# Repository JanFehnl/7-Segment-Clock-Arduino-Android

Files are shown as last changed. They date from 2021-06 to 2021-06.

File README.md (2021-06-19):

# 7 Segment Clock Arduino Android
This is an digital 7 segment clock controlled with an Arduino and an android smartphone via Bluetooth. You don't need a real time clock module.

## Required Components:
  1. Arduino Nano or similar
  2. Low Energy Bluetooth Module (HC-05 oder similar)
  3. 220Ω resistor
  4. 12V power supply with Terminal
  5. 1.5m WS2811 LED-Strip
  6. wires
  7. 4 nails
  8. 16 M3*5+ bolts with nuts

## Step by step guide:
  1. 3D print the clock
      - Black:
        - 1 * MainLO.stl ①
        - 1 * MainLI.stl
        - 1 * MainRI.stl
        - 1 * MainRO.stl
        - 2 * Middle.stl
      - White:
        - 30 * Segment.stl (Layer Height = 0.1mm && Vase Mode on)
  3. Upload the Arduino Sketch to the Arduino.
  4. solder the components as shown in the following picture:

PlanFinal

4. Download the Android App from the Google Play Store:
https://play.google.com/store/apps/details?id=com.JanFehnl.Uhr

5. If the time is not exact, then change the value of the variable "TimeCorrection" in the Arduino Sketch so that the deviation of the time is as small as possible. If the clock is slow, then increase the value slightly, if the clock is fast, then decrease the value of the variable.

① If you have the Arduino outside the clock and only need the three cables to the LED strip, then use V1. If you want to mount the Arduino and the terminal of the 12V power supply inside the clock, then print V2 to be able to lead the two cables into the clock.

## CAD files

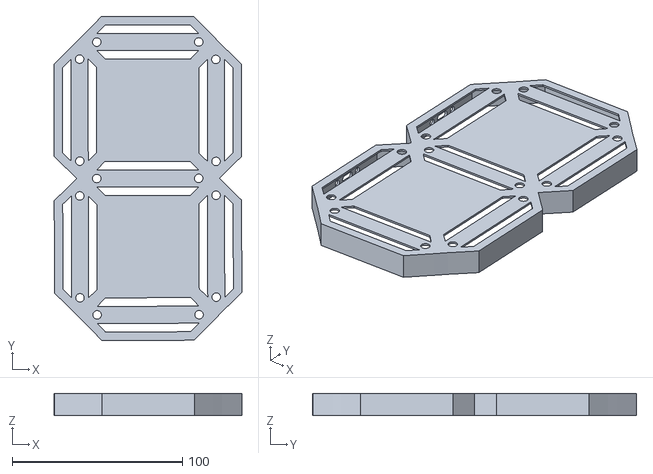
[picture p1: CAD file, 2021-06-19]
3DModels/MainLOV2.stl
110.1 x 190.1 x 13.0

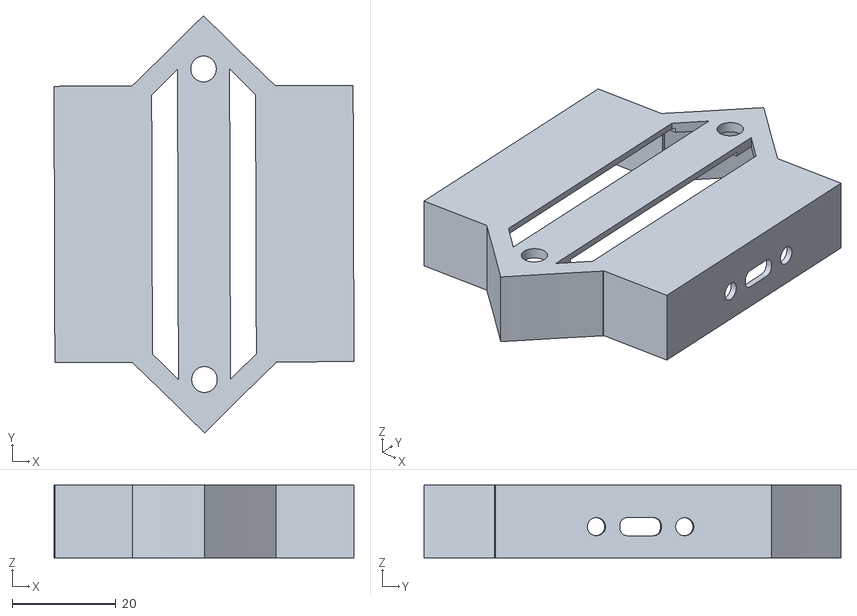
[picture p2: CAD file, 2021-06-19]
3DModels/Middle.stl
57.8 x 80.3 x 14.0

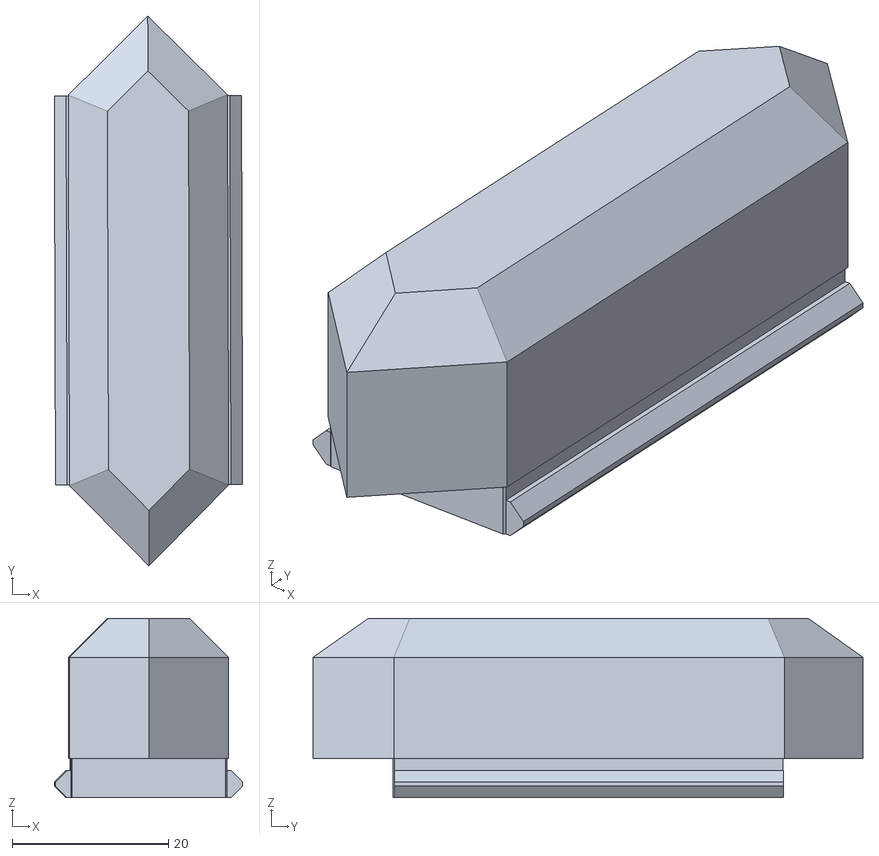
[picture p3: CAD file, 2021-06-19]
3DModels/Segment.stl
24.2 x 70.5 x 23.0

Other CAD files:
3DModels/MainLOV1.stl
3DModels/MainLI.stl
3DModels/MainLO.stl
3DModels/MainRO.stl
3DModels/MainRI.stl

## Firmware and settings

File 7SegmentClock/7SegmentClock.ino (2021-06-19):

#include <FastLED.h>

#define Num_Strip1 30
struct CRGB Strip1[Num_Strip1];

byte Red[5] = {255, 255, 255, 255};
byte Green[5] = {255, 255, 255, 255};
byte Blue[5] = {255, 255, 255, 255};
byte State;
byte Sekunde = 0;
byte MinuteUmspringen;
bool ValueIsComing = false;
unsigned long timeNow = 0;
unsigned long timeLast = 0;
int seconds = 0;
int minutes = 33;
int hours = 12;
int TimeCorrection = 1060;
int CaseNum;
char Case;

void setup()
{
  Serial.begin(9600);
  FastLED.addLeds<WS2811, 6, BRG>(Strip1, Num_Strip1);
}

void loop()
{
  timeNow = millis() / TimeCorrection;
  seconds = timeNow - timeLast;

  Sekunde = seconds;
  int ZeitInSekunden = Sekunde;
  int Minute = minutes;
  int Stunde = hours;

  if (MinuteUmspringen != Minute)
  {
    ShowDigit(0, Stunde / 10, 0);
    ShowDigit(7, Stunde % 10, 1);
    ShowDigit(16, Minute / 10, 2);
    ShowDigit(23, Minute % 10, 3);
    MinuteUmspringen = Minute;
  }
  if (ZeitInSekunden % 2 == 1)
  {
    Strip1[14] = CRGB(Red[4], Green[4], Blue[4]);
    Strip1[15] = CRGB(Red[4], Green[4], Blue[4]);
  }
  else
  {
    Strip1[14] = CRGB(Red[4] / 5, Green[4] / 5, Blue[4] / 5);
    Strip1[15] = CRGB(Red[4] / 5, Green[4] / 5, Blue[4] / 5);
  }

  if (seconds == 60)
  {
    timeLast = timeNow;
    minutes = minutes + 1;
  }

  if (minutes == 60)
  {
    minutes = 0;
    hours = hours + 1;
  }

  if (Serial.available())
  {
    if (ValueIsComing)
    {
      long int a = Serial.read();
      if (Case == 'a')
      {
        switch (CaseNum)
        {
        case 0:
          hours = a;
          CaseNum++;
          break;

        case 1:
          minutes = a;
          CaseNum++;
          break;

        case 2:
          timeLast = timeNow - a;
          ValueIsComing = false;
          break;

        default:
          break;
        }
      }
      else if (Case == 'b')
      {
        switch (CaseNum)
        {
        case 0:
          State = a;
          CaseNum++;
          break;

        case 1:
          if (State == 0 || State == 1 || State == 2 || State == 3)
          {
            Red[State] = a;
          }
          else if (State == 4)
          {
            Red[0] = a;
            Red[1] = a;
          }
          else if (State == 5)
          {
            Red[2] = a;
            Red[3] = a;
          }
          else if (State == 6)
          {
            Red[0] = a;
            Red[1] = a;
            Red[2] = a;
            Red[3] = a;
            Red[4] = a;
          }
          else if (State == 7)
          {
            Red[4] = a;
          }
          CaseNum++;
          break;

        case 2:
          if (State == 0 || State == 1 || State == 2 || State == 3)
          {
            Green[State] = a;
          }
          else if (State == 4)
          {
            Green[0] = a;
            Green[1] = a;
          }
          else if (State == 5)
          {
            Green[2] = a;
            Green[3] = a;
          }
          else if (State == 6)
          {
            Green[0] = a;
            Green[1] = a;
            Green[2] = a;
            Green[3] = a;
            Green[4] = a;
          }
          else if (State == 7)
          {
            Green[4] = a;
          }
          CaseNum++;
          break;

        case 3:
          if (State == 0 || State == 1 || State == 2 || State == 3)
          {
            Blue[State] = a;
          }
          else if (State == 4)
          {
            Blue[0] = a;
            Blue[1] = a;
          }
          else if (State == 5)
          {
            Blue[2] = a;
            Blue[3] = a;
          }
          else if (State == 6)
          {
            Blue[0] = a;
            Blue[1] = a;
            Blue[2] = a;
            Blue[3] = a;
            Blue[4] = a;
          }
          else if (State == 7)
          {
            Blue[4] = a;
          }
          MinuteUmspringen--;
          ValueIsComing = false;
          break;

        default:
          break;
        }
      }
    }
    else
    {
      char a = Serial.read();
      switch (a)
      {
      case 'a':
        Case = a;
        CaseNum = 0;
        ValueIsComing = true;
        break;

      case 'b':
        Case = a;
        CaseNum = 0;
        ValueIsComing = true;
        break;

      default:
        break;
      }
    }
  }
  FastLED.show();
}

void ShowDigit(int StartPosition, int Digit, int Num)
{
  FastLED.setBrightness(255);
  for (int a = StartPosition; a <= StartPosition + 7; a++)
  {
    Strip1[a] = CHSV(255, 255, 0);
  }
  if (Digit == 0)
  {
    Strip1[StartPosition + 1] = CRGB(Red[Num], Green[Num], Blue[Num]);
    Strip1[StartPosition + 2] = CRGB(Red[Num], Green[Num], Blue[Num]);
    Strip1[StartPosition + 3] = CRGB(Red[Num], Green[Num], Blue[Num]);
    Strip1[StartPosition + 4] = CRGB(Red[Num], Green[Num], Blue[Num]);
    Strip1[StartPosition + 5] = CRGB(Red[Num], Green[Num], Blue[Num]);
    Strip1[StartPosition + 6] = CRGB(Red[Num], Green[Num], Blue[Num]);
  }
  else if (Digit == 1)
  {
    Strip1[StartPosition + 1] = CRGB(Red[Num], Green[Num], Blue[Num]);
    Strip1[StartPosition + 6] = CRGB(Red[Num], Green[Num], Blue[Num]);
  }
  else if (Digit == 2)
  {
    Strip1[StartPosition] = CRGB(Red[Num], Green[Num], Blue[Num]);
    Strip1[StartPosition + 1] = CRGB(Red[Num], Green[Num], Blue[Num]);
    Strip1[StartPosition + 2] = CRGB(Red[Num], Green[Num], Blue[Num]);
    Strip1[StartPosition + 4] = CRGB(Red[Num], Green[Num], Blue[Num]);
    Strip1[StartPosition + 5] = CRGB(Red[Num], Green[Num], Blue[Num]);
  }
  else if (Digit == 3)
  {
    Strip1[StartPosition] = CRGB(Red[Num], Green[Num], Blue[Num]);
    Strip1[StartPosition + 1] = CRGB(Red[Num], Green[Num], Blue[Num]);
    Strip1[StartPosition + 2] = CRGB(Red[Num], Green[Num], Blue[Num]);
    Strip1[StartPosition + 5] = CRGB(Red[Num], Green[Num], Blue[Num]);
    Strip1[StartPosition + 6] = CRGB(Red[Num], Green[Num], Blue[Num]);
  }
  else if (Digit == 4)
  {
    Strip1[StartPosition] = CRGB(Red[Num], Green[Num], Blue[Num]);
    Strip1[StartPosition + 1] = CRGB(Red[Num], Green[Num], Blue[Num]);
    Strip1[StartPosition + 3] = CRGB(Red[Num], Green[Num], Blue[Num]);
    Strip1[StartPosition + 6] = CRGB(Red[Num], Green[Num], Blue[Num]);
  }
  else if (Digit == 5)
  {
    Strip1[StartPosition] = CRGB(Red[Num], Green[Num], Blue[Num]);
    Strip1[StartPosition + 2] = CRGB(Red[Num], Green[Num], Blue[Num]);
    Strip1[StartPosition + 3] = CRGB(Red[Num], Green[Num], Blue[Num]);
    Strip1[StartPosition + 5] = CRGB(Red[Num], Green[Num], Blue[Num]);
    Strip1[StartPosition + 6] = CRGB(Red[Num], Green[Num], Blue[Num]);
  }
  else if (Digit == 6)
  {
    Strip1[StartPosition] = CRGB(Red[Num], Green[Num], Blue[Num]);
    Strip1[StartPosition + 2] = CRGB(Red[Num], Green[Num], Blue[Num]);
    Strip1[StartPosition + 3] = CRGB(Red[Num], Green[Num], Blue[Num]);
    Strip1[StartPosition + 4] = CRGB(Red[Num], Green[Num], Blue[Num]);
    Strip1[StartPosition + 5] = CRGB(Red[Num], Green[Num], Blue[Num]);
    Strip1[StartPosition + 6] = CRGB(Red[Num], Green[Num], Blue[Num]);
  }
  else if (Digit == 7)
  {
    Strip1[StartPosition + 1] = CRGB(Red[Num], Green[Num], Blue[Num]);
    Strip1[StartPosition + 2] = CRGB(Red[Num], Green[Num], Blue[Num]);
    Strip1[StartPosition + 6] = CRGB(Red[Num], Green[Num], Blue[Num]);
  }
  else if (Digit == 8)
  {
    Strip1[StartPosition] = CRGB(Red[Num], Green[Num], Blue[Num]);
    Strip1[StartPosition + 1] = CRGB(Red[Num], Green[Num], Blue[Num]);
    Strip1[StartPosition + 2] = CRGB(Red[Num], Green[Num], Blue[Num]);
    Strip1[StartPosition + 3] = CRGB(Red[Num], Green[Num], Blue[Num]);
    Strip1[StartPosition + 4] = CRGB(Red[Num], Green[Num], Blue[Num]);
    Strip1[StartPosition + 5] = CRGB(Red[Num], Green[Num], Blue[Num]);
    Strip1[StartPosition + 6] = CRGB(Red[Num], Green[Num], Blue[Num]);
  }
  else if (Digit == 9)
  {
    Strip1[StartPosition] = CRGB(Red[Num], Green[Num], Blue[Num]);
    Strip1[StartPosition + 1] = CRGB(Red[Num], Green[Num], Blue[Num]);
    Strip1[StartPosition + 2] = CRGB(Red[Num], Green[Num], Blue[Num]);
    Strip1[StartPosition + 3] = CRGB(Red[Num], Green[Num], Blue[Num]);
    Strip1[StartPosition + 5] = CRGB(Red[Num], Green[Num], Blue[Num]);
    Strip1[StartPosition + 6] = CRGB(Red[Num], Green[Num], Blue[Num]);
  }
}
